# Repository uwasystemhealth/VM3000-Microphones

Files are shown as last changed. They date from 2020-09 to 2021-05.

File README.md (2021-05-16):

# VM3000-Microphones

This project was completed by Ricky Leman under the supervision of Dr Ben Travaglione and Professor Melinda Hodkiewicz as part of the UWA Master of Professional Engineering research units GENG5511 & GENG5512.

This project involves the design, build and testing of a microphone array prototype which implements a pair of Vesper VM3000 MEMS microphones.

This repository and the time_domain_beamforming repository - https://github.com/uwasystemhealth/time_domain_beamforming contains all relevant files for the VM3000 PDM microphone array beamforming project.

All collected test data can be found in the time_domain_beamforming repository

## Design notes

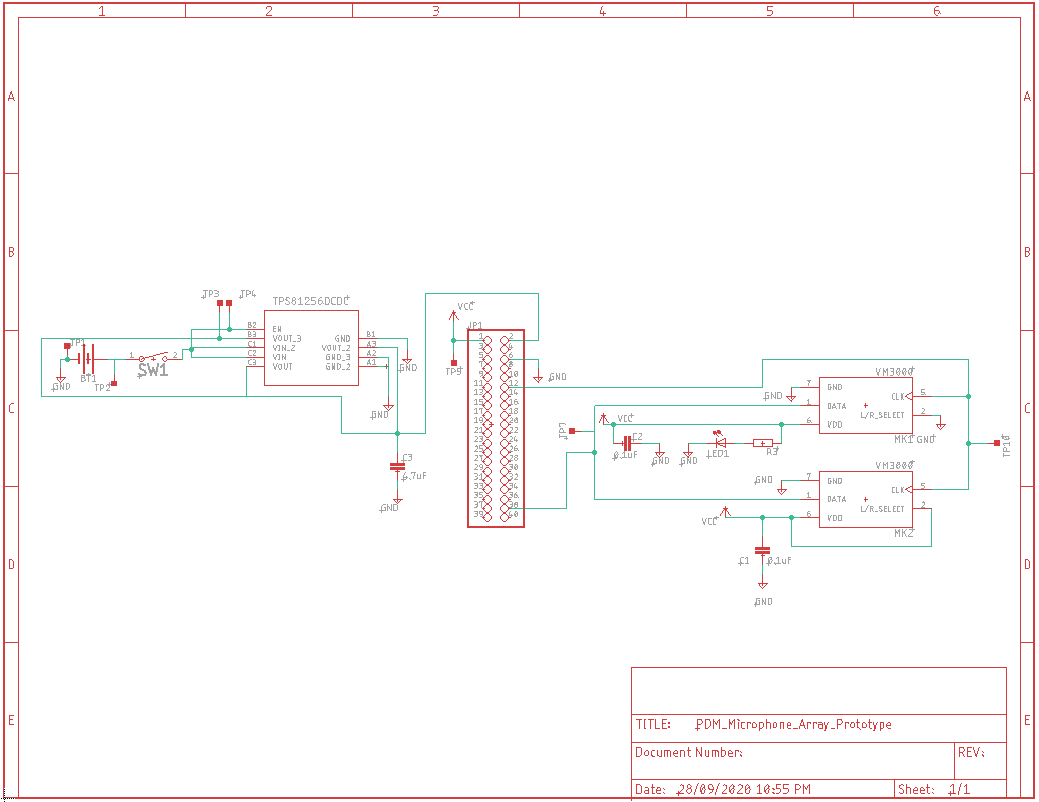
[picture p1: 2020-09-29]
Images/PDM_Microphone_Array_Prototype_Schematic.PNG

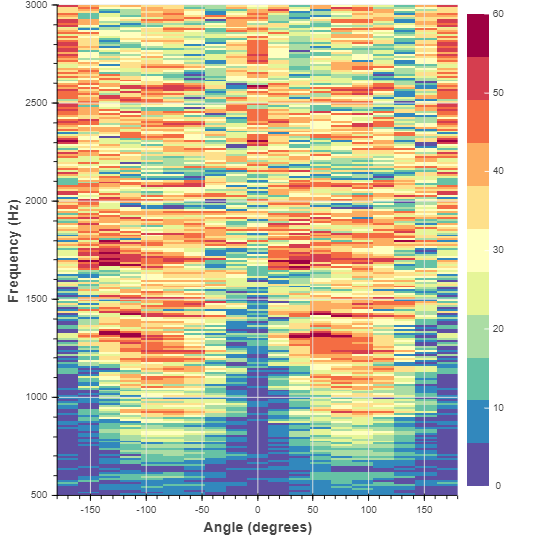
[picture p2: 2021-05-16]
Images/Heatmap_Thesis_Non_Anechoic_FINAL.png

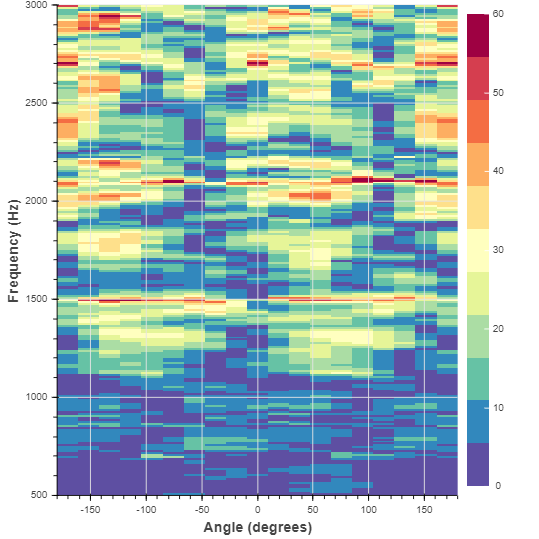
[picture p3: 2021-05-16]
Images/Heatmap_Thesis_Anechoic_FINAL.png

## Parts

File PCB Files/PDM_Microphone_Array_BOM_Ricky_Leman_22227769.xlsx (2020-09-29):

Item | Description | Manufacturer | Manufacturer Part Number | Supplier | Supplier Part Number 1 | Quantity | Unit Price (AUD) | Extended Price (AUD) | Availibility
1 | Switch slide SPST 8.5A 125V | CW Industries | GF-123-0054 | Digi-Key | CWI333-ND | 5 | 1.81 | 9.05 | Immediate
2 | IC Reg Boost 5V 9USIP | Texas Instruments | TPS81256SIPR | Digi-Key | 296-30558-1-ND | 5 | 3.64 | 18.2 | Immediate
3 | Ceramic Capacitor 0.1 uF 16V Y5V 0402 | KEMET | C0402C104Z4VAC7867 | Digi-Key | 399-1043-1-ND | 10 | 0.023 | 0.23 | Immediate
4 | Ceramic Capacitor 4.7 uF 16V X7R 1206 | Samsung Electro-Mechanics | CL31B475KOHNNNE | Digi-Key | 1276-3182-1-ND | 10 | 0.246 | 2.46 | Immediate
5 | LED Green Clear 2SMD | Kingbright | APT2012LZGCK | Digi-Key | 754-1939-1-ND | 5 | 0.81 | 4.05 | Immediate
6 | Resistor 330 Ohm SMD 1% 1/8W 0805 | Bourns Inc. | CR0805-FX-3300ELF | Digi-Key | 118-CR0805-FX-3300ELFCT-ND | 5 | 0.14 | 0.7 | Immediate
7 | Battery Contact Clip 18650 PC Pin | Keystone Electronics | 54 | Digi-Key | 36-54-ND | 10 | 0.91 | 9.1 | Immediate
8 | GPIO Female Header Raspberry Pi | Adafruit Industries LLC | 2222 | Digi-Key | 1528-1785-ND | 5 | 2.17 | 10.85 | Immediate
9 | GPIO Male Header Raspberry Pi | SparkFun Electronics | PRT-14275 | Digi-Key | 1568-1675-ND | 4 | 1.37 | 5.48 | Immediate
 |  |  |  |  |  |  | Total Price (AUD) | 60.12

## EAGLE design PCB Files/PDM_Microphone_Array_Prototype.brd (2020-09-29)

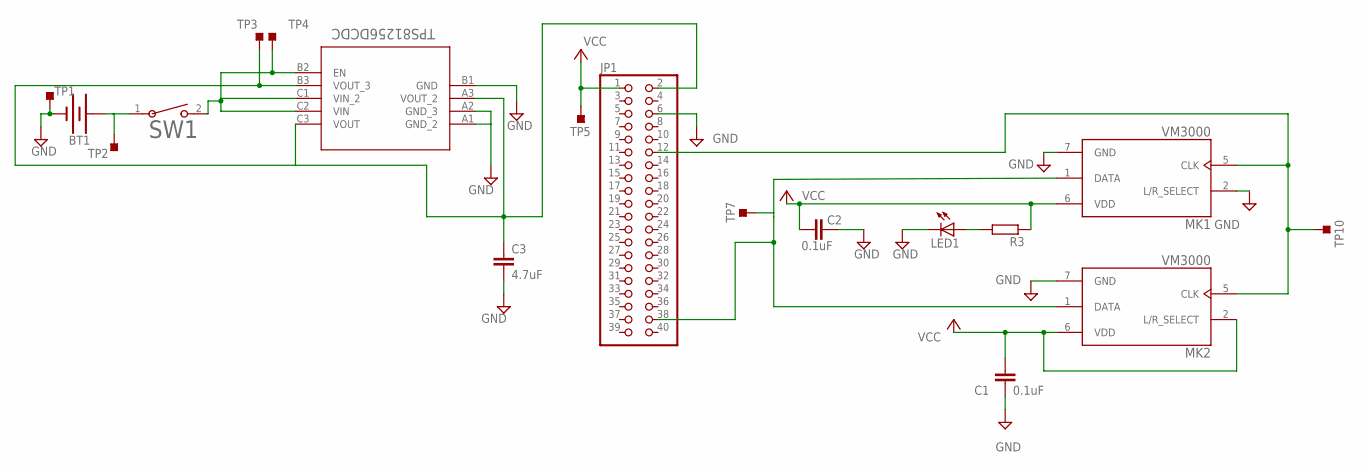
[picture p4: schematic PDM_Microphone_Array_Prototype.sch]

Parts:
BT1: BATTERY-18650; BATTERY_18650-HOLDER
C1, C2: 0.1uF; 0402
C3: 4.7uF; 1206
JP1: PINHD-2X20; 2X20
LED1: LEDCHIPLED_0805; CHIPLED_0805
MK1, MK2: VM3000; MIC_VM3000
R3: R-EU_R0805; R0805
SW1: GF-123-0054; SW2_GF-123-0054_CWI
TP1, TP2, TP3, TP4, TP5, TP7, TP10: TESTPOINT_TPS-PAD-036; TESTPOINT_PAD-036
TPS81256DCDC: TPS81256SIPRUSIP9_SIP_TEX-L; USIP9_SIP_TEX-L

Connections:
GND: BT1.GND@1 (-), C1.2, C2.1, C3.2, JP1.6, LED1.C, MK1.2 (L/R_SELECT), MK1.7 (GND), MK2.7 (GND), TP1.1, TPS81256DCDC.A1 (GND_2), TPS81256DCDC.A2 (GND_3), TPS81256DCDC.B1 (GND)
unnamed: JP1.38, MK1.1 (DATA), MK2.1 (DATA), TP7.1
unnamed: JP1.12, MK1.5 (CLK), MK2.5 (CLK), TP10.1
unnamed: LED1.A, R3.2
unnamed: SW1.2, TP4.1, TPS81256DCDC.B2 (EN), TPS81256DCDC.C1 (VIN_2), TPS81256DCDC.C2 (VIN)
unnamed: C3.1, JP1.2, TP3.1, TPS81256DCDC.A3 (VOUT_2), TPS81256DCDC.B3 (VOUT_3), TPS81256DCDC.C3 (VOUT)
unnamed: BT1.PWR@1 (+), SW1.1, TP2.1
VCC: C1.1, C2.2, JP1.1, MK1.6 (VDD), MK2.2 (L/R_SELECT), MK2.6 (VDD), R3.1, TP5.1

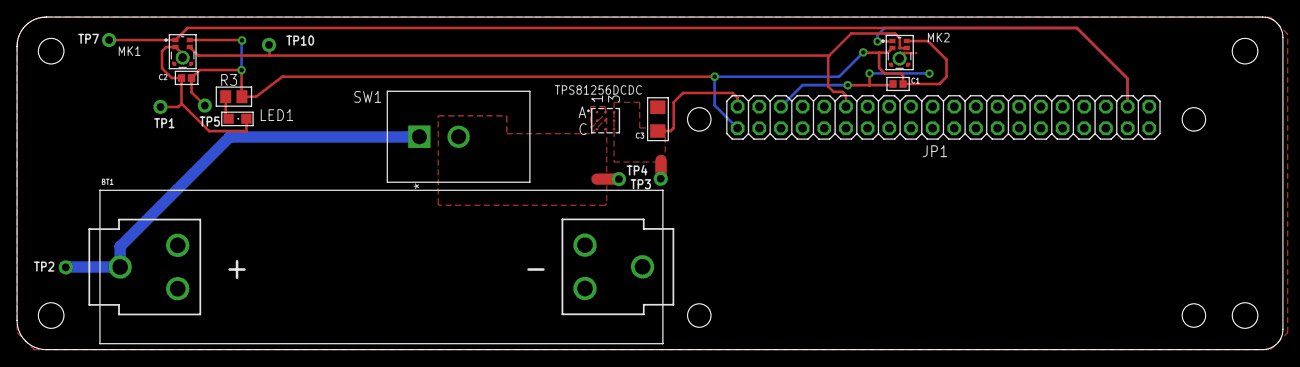
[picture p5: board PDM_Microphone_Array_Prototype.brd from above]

Board: 2 copper layers, 148.4 x 39.0 mm, 18 parts (0 on the bottom side), 8 nets.

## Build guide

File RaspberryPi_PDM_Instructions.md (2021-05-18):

## Raspberry Pi Zero W PDM Mode Setup

<b> Note as of 16/05/2021, the following instructions have also been tested on the Raspberry Pi 4 Model B and successfully enables PDM audio </b> 

<b> RPi version: 4.19.88+ </b>

<b> Relevant links: </b>
 - https://www.raspberrypi.org/forums/search.php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
 - https://github.com/imec-int/Raspberry-Pi-Installer-Scripts

The RPi's SoC (BCM2835) is not configured to take PDM data as an input on its I2S line, however it is capable of interfacing with 2 PDM microphones. To enable PDM input, these are the specific steps that I followed:

Navigate to the BCM2835 sound source file (bcm2835-i2s.c) location by doing the following:
 
```bash
cd linux/sound/soc/bcm
```

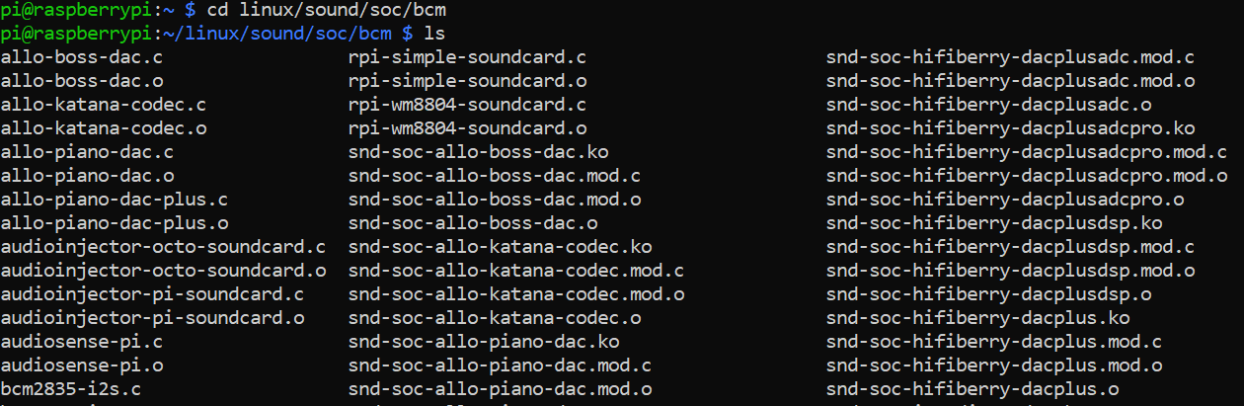
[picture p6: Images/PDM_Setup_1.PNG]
bcm directory


Open the BCM2835 I2S sound source file for editing in root mode

```bash
sudo nano bcm2835-i2s.c
```

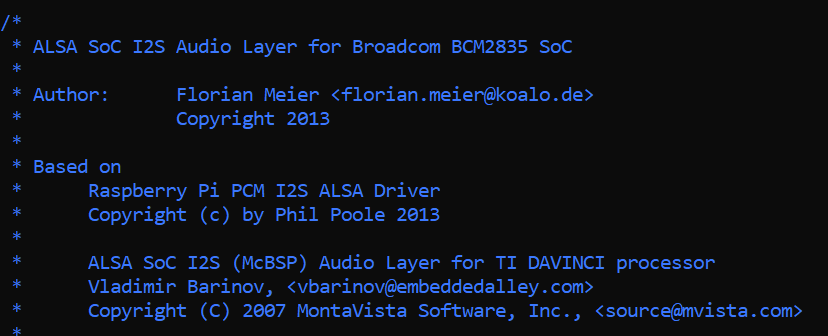
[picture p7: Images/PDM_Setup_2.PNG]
bcm2835-i2s.c


Make the following edits in the sound source file to ensure PDM is enabled correctly - here we are using bitwise OR to write 1 to the relevant PDM registers which you can find in the BCM2835 SOC datasheet:
 - Go to line ~393/394 and write "bclk_rate = 307200" (This fixes the PCM clockrate at 3.072 MHz which is what we generally need for PDM microphones - note this may be unique for different microphones, check your relevant datasheet)
 - Go to line ~586 and write "mode |= BCM2835_I2S_PDMN;" on one line and "mode |= BCM2835_I2S_PDME" on the next line. Note this should be done before the existing command in the file "regmap_write(dev->i2s_regmap, BCM2835_I2S_MODE_A_REG, mode);" (This enables PDM mode and selects a decimation factor of N = 32)
 
Be sure to save the changes made to the sound source file.  

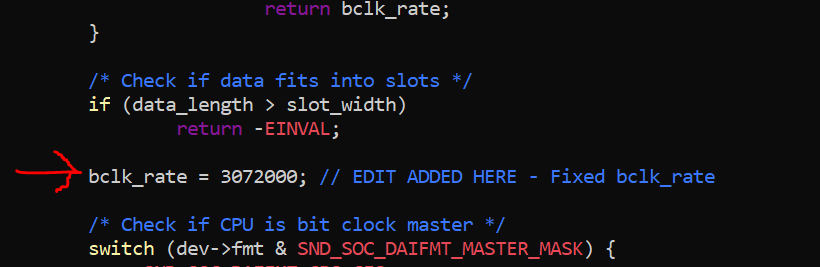
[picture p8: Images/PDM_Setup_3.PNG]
Change bclk_rate


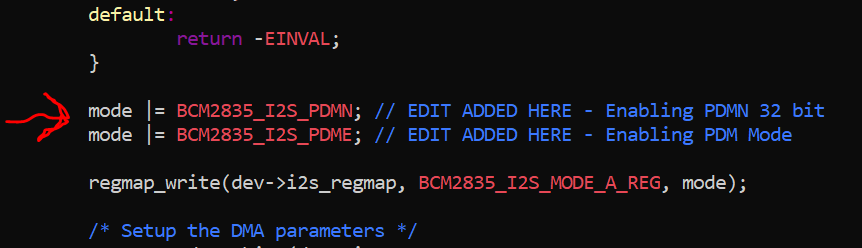
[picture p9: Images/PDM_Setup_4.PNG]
Change BCM mode


Now that we have changed the source file, we use the 'make' command to run the MakeFile which compiles all changes and generates a .ko kernel object:
    
```bash
make -C /lib/modules/(\\$ uname -r)/build M=(\$ pwd)
```

You should see a bunch of files with .c, .o and .ko extensions - look out for the file named `snd-soc-bcm2835-i2s.ko`. This is the file which captures changes made in the `bcm2835-i2s.c` file.

snd-soc-bcm2835-i2s.ko

Now we have to navigate to the directory of the kernel which contains the existing "snd-soc-bcm2835-i2s.ko" which needs to be replaced. Once we are there, we need to remove the existing kernel object so we can replace it with the newly generated one:

```bash
cd lib/modules/(uname -r)/kernel/sound/soc/bcm

sudo rm -r snd-soc-bcm2835-i2s.ko
```

replace file

Now we navigate back to the location of our <b> new </b> "snd-soc-bcm2835-i2s.ko" kernel object and copy this over to the kernel directory in which we have just deleted the existing sound kernel object:

```bash
sudo cp snd-soc-bcm2835-i2s.ko /lib/modules/($ uname -r)/kernel/sound/soc/bcm
```

Reboot the pi and test your PDM audio recording using the `arecord` command.

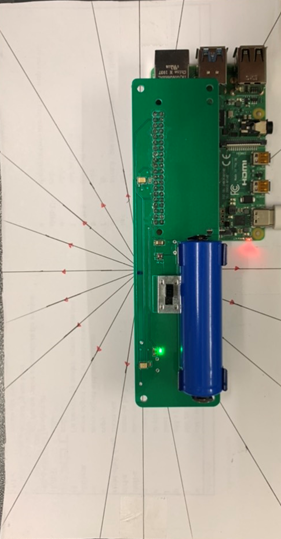
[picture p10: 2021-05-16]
Images/Setup_5.png

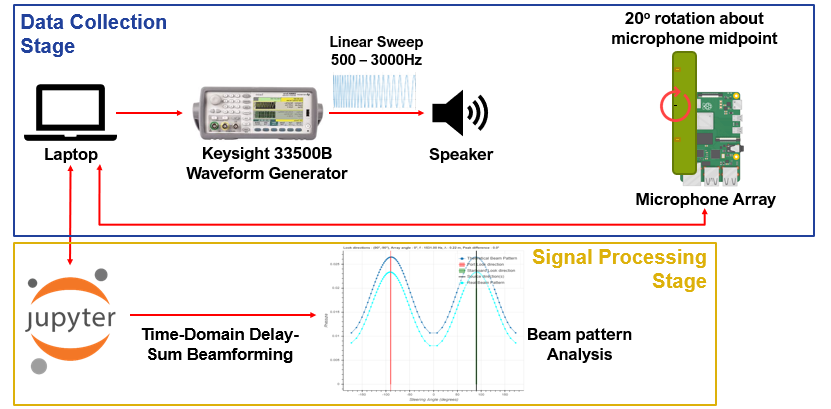
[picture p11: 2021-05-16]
Images/Experimental Data Collection Setup.png

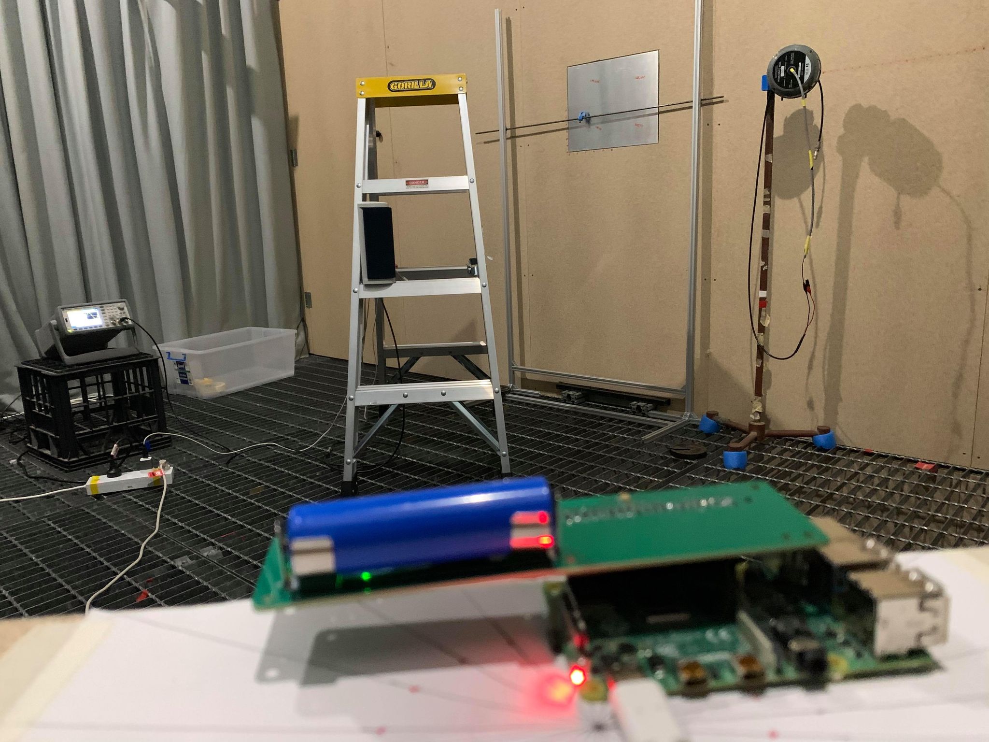
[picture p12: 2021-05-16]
Images/Anechoic_Setup_2.jpg

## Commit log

2020-07-29 Added note about inserting images
2020-09-29 Added prototype PCB design section
2020-09-29 Added PCB relevant images and files
    [PDM_Microphone_Array_BOM_Ricky_Leman_22227769.xlsx, PDM_Microphone_Array_Prototype.brd, PDM_Microphone_Array_Prototype.sch]
2020-10-13 Added microphone array BOM
    [PDM_Microphone_Array_BOM_Ricky_Leman_22227769.xlsx]
2020-10-23 Added populated PCB prototype images
2020-10-23 Updated microphone array assembly section
2021-02-26 Added code to conduct board frequency characterisation tests
2021-05-16 Added notebook used for experimental data collection
    Used to control Keysight 33500B Waveform Generator, connect to RPi and collect test data.
    Used in UWA Anechoic Chamber and UWA SHL room.
2021-05-16 Cleaning repo
    [PDM_Microphone_Array_BOM_Ricky_Leman_22227769.xlsx]
2021-05-18 Replaced RaspberryPi_PDM_Instructions notebook with markdown file

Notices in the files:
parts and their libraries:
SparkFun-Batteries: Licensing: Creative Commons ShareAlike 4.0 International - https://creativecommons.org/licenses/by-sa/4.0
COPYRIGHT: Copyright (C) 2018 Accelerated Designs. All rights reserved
